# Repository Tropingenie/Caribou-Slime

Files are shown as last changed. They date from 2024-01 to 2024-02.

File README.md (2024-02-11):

SlimeVR PCB using ESP32-C3 and BMI 270
## Methodology
This design is intended to be assembled either completely by hand, or with some PCBA and finished by hand. Component selection is built around this, prioritizing larger form factor SMT components where possible, to ensure compatibility with and minimizing cost of the PCBA, while maintaining relatively simple assembly when done by hand.
## BOM
| Component | Choice | Amount | Cost per | Cost with Shipping | Quick Link |
|:---:|:---:|:---:|:---:|:---:|:---:|
| Microcontroller | ESP32-C3 Supermini Dev Board | 12 | $2.90 | ~$41 | [AliExpress](https://www.aliexpress.com/item/1005005877531694.html), [Datasheet](https://www.tindie.com/products/adz1122/esp32-c3-development-board-esp32-supermini/), [Schematic](https://s11.ax1x.com/2023/06/26/pCUheR1.png) |
| IMU | BMI270 | 12 | $1.75 | ~$26 | [AliExpress](https://www.aliexpress.com/item/1005005001642144.html), [Datasheet](https://www.mouser.ca/datasheet/2/783/bst_bmi270_ds000-2529306.pdf), [Schematic](https://web.archive.org/web/20240115041534/http://cdn.kouno.xyz/pKyF5w64.pdf) |
| Batteries | 603040 800mAh | 10 | $3.50 | ~$31 | [AliExpress](https://www.aliexpress.com/item/1005005413532176.html) |
| Charging Board  | TP4056 USB-C | 15 | $0.329 | ~$5 | [AliExpress](https://www.aliexpress.com/item/1005005708749053.html) |
| Power Switches  | EG1270/MSK-12D19 | 10 | $0.085 | ~$3 | [EG Datasheet](https://www.snapeda.com/parts/EG1270/E-Switch/datasheet/), [MSK Datasheet](http://www.intechswitch.com/products/SideKnobToggleslideswitchseries/641.html), [MSK AliExpress](https://www.aliexpress.com/item/1005006241343643.html) |
| Diodes | B5817W | 50 | | ~$3 | [AliExpress](https://www.aliexpress.com/item/1005005562043696.html), [Datasheet](https://jlcpcb.com/partdetail/Hongjiacheng-B5817W/C7420328) |
| Resistors | 0805 180k 5% (See schematic) | 100 | | ~$2 | [AliExpress](https://www.aliexpress.com/item/4000996637737.html) |
| Resistors | 0805 10k 5% (See schematic)  | 100 | | ~$2 | [AliExpress](https://www.aliexpress.com/item/4000996637737.html) |
| Capacitors | 0805 100nF 5% (See schematic)| 100 | | ~$2 | [AliExpress](https://www.aliexpress.com/item/1005006285113165.html) |
| PCB | Upload Gerbers | 5 | $0.538 | ~$4 | [JLCPCB](https://jlcpcb.com/) |
## Acknowledgement
EDA files are from various sources, since there is no point in reinventing the wheel. At this stage, they are assumed to be correct, but have not been tested for accuracy.
- [BMI270](https://www.snapeda.com/parts/BMI270/Bosch%20Sensortec/view-part/) from SnapEDA
- [ESP32 C2 SuperMini](https://www.snapeda.com/parts/ESP32-C3%20SuperMini/Espressif%20Systems/view-part/) from SnapEDA
- [TP4056 Charging Board](https://www.youtube.com/watch?v=d5fERUHO1Lw) footprint copied from YouTube, schematic by observation
- [EG1270](https://www.snapeda.com/parts/EG1270/E-Switch/view-part/) from SnapEDA

Assistance from various sources was used in this project, in addition to readily available datasheets. In particular, the following people and sources have contributed to this project:
- [SlimeVR Docs](https://docs.slimevr.dev/diy/index.html) for general SlimeVR schematics
- [SlimeVR Discord](https://discord.gg/SlimeVR) for general assisance
- [KounoLab](https://store.kouno.xyz/products/bmi270-breakout-board) for additional BMI270 schematics
- @simp_360 on Discord for diode and passive component selection
- [Lupinixx](https://github.com/Lupinixx/SlimeVR-Hyperion-BMI160-PCB) and [Smeltie](https://github.com/Smeltie/Hyperion) for the Hyperion case and board outline

## License
This project is licensed under the CERN Open Hardware Licence Version 2 - Strongly Reciprocal. See [LICENSE](LICENSE) for full DEP5 formatted REUSE compliant listing of all licensing. For instructions on how to use this design, please refer to the CERN-OHL-S [user guide](cern_ohl_s_v2_user_guide.pdf).

>Copyright Pon Pon 2024.\
This source describes Open Hardware and is licensed under the CERN-OHL-S v2.
You may redistribute and modify this source and make products using it under the terms of the [CERN-OHL-S v2](https://ohwr.org/cern_ohl_s_v2.txt).\
This source is distributed WITHOUT ANY EXPRESS OR IMPLIED WARRANTY, INCLUDING OF MERCHANTABILITY, SATISFACTORY QUALITY AND FITNESS FOR A PARTICULAR PURPOSE. Please see the CERN-OHL-S v2 for applicable conditions.\
Source location: https://github.com/Tropingenie/Caribou-Slime \
As per CERN-OHL-S v2 section 4, should You produce hardware based on this source, You must where practicable maintain the Source Location visible on the silkscreen of the PCB or other products you make using this source.

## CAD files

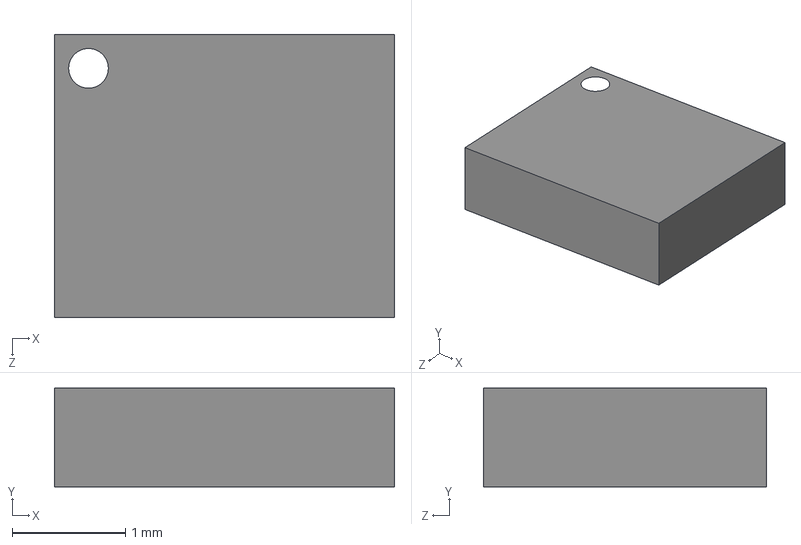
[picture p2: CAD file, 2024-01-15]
eCAD/BMI270/BMI270.step
3.00 x 0.87 x 2.50 mm

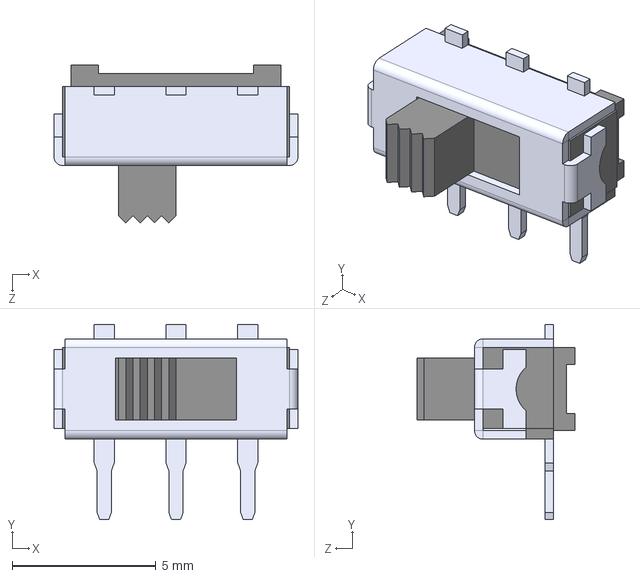
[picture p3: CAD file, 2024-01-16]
eCAD/EG1270/EG1270.step
8.50 x 6.80 x 5.50 mm

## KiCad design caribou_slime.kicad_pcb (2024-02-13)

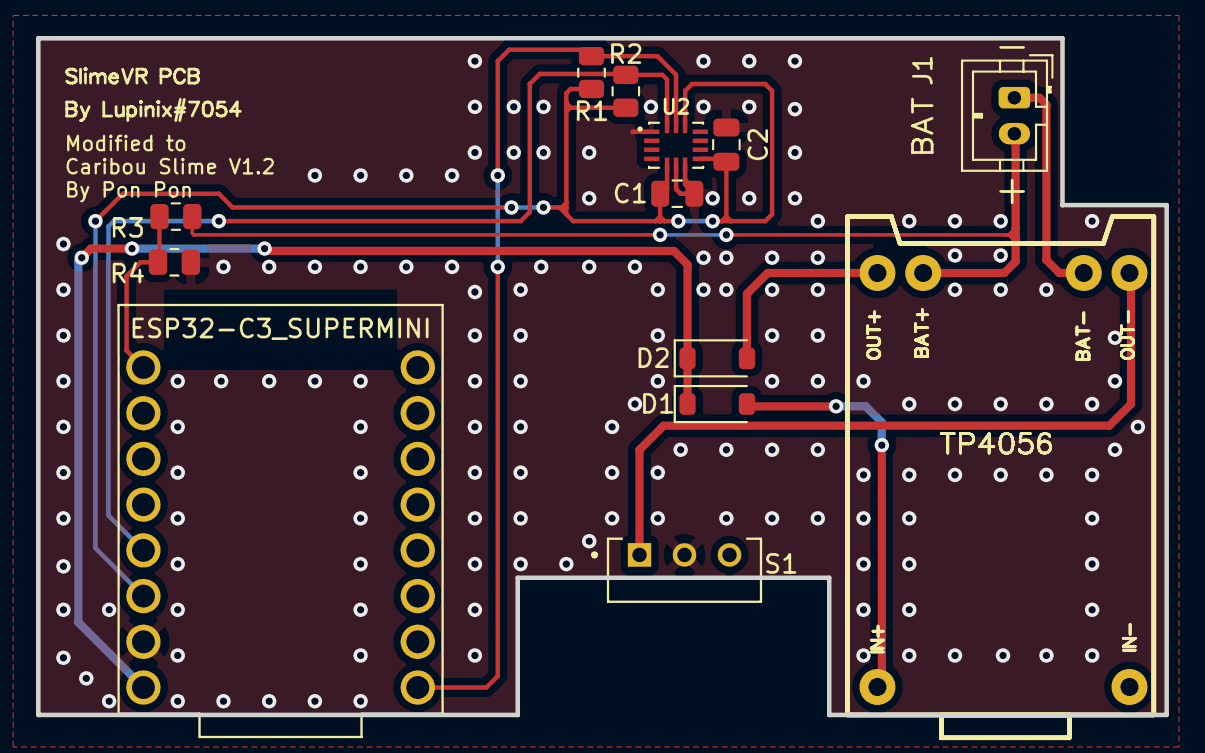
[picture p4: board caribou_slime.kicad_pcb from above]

Board: 2 copper layers, 62.7 x 37.6 mm, 13 parts (0 on the bottom side), 11 nets.

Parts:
C1, C2: 100nF; C_0805_2012Metric
D1, D2: B5817W; D_SOD-123
J1: Conn_01x02_MountingPin; JST_PH_B2B-PH-K_1x02_P2.00mm_Vertical
R1, R2: 10k; R_0805_2012Metric
R3, R4: 180k; R_0805_2012Metric
S1: EG1270; SW_EG1270
U1: ESP32-C3_SUPERMINI; MODULE_ESP32-C3_SUPERMINI
U2: BMI270; XDCR_BMI270
U3: TP4056; TP4056 Charging Board

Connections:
+3V3: C1.1, C2.1, R1.1, R2.1, U1.3.3 (3V3), U2.5 (VDDIO), U2.8 (VDD), U2.12 (CSB)
+5V: D1.1 (K), D2.1 (K), U1.5V
/B+: J1.2, R3.1, U3.5 (B+)
/B-: J1.1, U3.6 (B-)
GND: C1.2, C2.2, R4.2, S1.2, U1.G (GND), U2.1 (SDO), U2.6 (GNDIO), U2.7 (GND)
unnamed: D1.2 (A), U3.1 (+)
unnamed: D2.2 (A), U3.3 (OUT+)
unnamed: R3.2, R4.1, U1.0 (GPIO0)
unnamed: S1.1, U3.4 (OUT-)
SCL: R1.2, U1.5 (GPIO5), U2.13 (SCX)
SDA: R2.2, U1.4 (GPIO4), U2.14 (SDX)

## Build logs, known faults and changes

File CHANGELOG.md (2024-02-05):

#### 1.1 (2024-02-05)
##### Chores

* **git:**  Update gitignore with Outputs folder ([e1761e18](https://github.com/Tropingenie/Caribou-Slime/commit/e1761e188d2f6d708ac8d7a0ce4b8d9b700f2ab1))
* **pcb:**
  *  Clean up SCL trace, stiching vias ([36fab2da](https://github.com/Tropingenie/Caribou-Slime/commit/36fab2da01eddbc8a2c2f9321ec0b02e734b0093))
  *  Run S1 trace ([f5dbebb2](https://github.com/Tropingenie/Caribou-Slime/commit/f5dbebb26b71ab781b65b740ba7b493cb27abcbf))
  *  Clear PCB for rework ([79724f06](https://github.com/Tropingenie/Caribou-Slime/commit/79724f06d09ecba5b7e15c69e1ae2038ea3d9b68))
  *  Clean up 3v3 trace ([33c8f8dc](https://github.com/Tropingenie/Caribou-Slime/commit/33c8f8dc0faf7752790b79c9067acac1a620ce24))
  *  Add stitching vias ([2086238c](https://github.com/Tropingenie/Caribou-Slime/commit/2086238c4812a27943edc295002db64d4f61f880))

##### Documentation Changes

* **pcb:**
  *  Fix silkscreen text ([fce9516e](https://github.com/Tropingenie/Caribou-Slime/commit/fce9516e328b0c797ed55c4b92e85ebc3e1f5b3a))
  *  Prep silk screen for V1.1 Hyperion layout ([3da79978](https://github.com/Tropingenie/Caribou-Slime/commit/3da79978956e21a994be3337dcc98d4a1b6263a4))
  *  Update silkscreen version number ([adf87a9c](https://github.com/Tropingenie/Caribou-Slime/commit/adf87a9cc52d62ae70a44fe4393f7fe04dcc25ed))
  *  Correct attribution and diode silkscreen ([97e8b304](https://github.com/Tropingenie/Caribou-Slime/commit/97e8b3044bba16a783717153758a67535e34dd04))
  *  Add versioning and github to silkscreen ([6df0c895](https://github.com/Tropingenie/Caribou-Slime/commit/6df0c8955d4412fe9c83a9e6ff428d9331b842d1))
* **git:**
  *  Add Hyperion attributions to README ([de8c5598](https://github.com/Tropingenie/Caribou-Slime/commit/de8c5598924c62871d16c71c90c9772a37134501))
  *  Add changelog ([6ed6fb8f](https://github.com/Tropingenie/Caribou-Slime/commit/6ed6fb8fb799e5b07e82560c993f4991915c10c9))

##### New Features

* **pcb:**  Design V1.1 PCB layout ([d03a254f](https://github.com/Tropingenie/Caribou-Slime/commit/d03a254f027ed8a3be3809fd5225acc5b23603d9))

##### Bug Fixes

* **pcb:**
  *  Update GPIO0 connection to voltage divider ([e8315e05](https://github.com/Tropingenie/Caribou-Slime/commit/e8315e059f23269145b51dfc6895d3f81c5e060e))
  *  Add correct JST schematic and footprint ([19320bd5](https://github.com/Tropingenie/Caribou-Slime/commit/19320bd59f4855a179c82c26a0f06b04f38bfdef))
  *  Add keep-out zone around antenna ([a4e4d6b1](https://github.com/Tropingenie/Caribou-Slime/commit/a4e4d6b14058ac6eb4f936a251781c287306000a))
  *  Add correct JST schematic and footprint ([ba236325](https://github.com/Tropingenie/Caribou-Slime/commit/ba236325d222b22f8554df80bf8a3fa0c63cf11f))
* **schematic:**
  *  Correct GPIO0 connection to voltage divider ([4021e6ab](https://github.com/Tropingenie/Caribou-Slime/commit/4021e6ab3e8be55155657b90452c1314c8ec476b))
  *  Switch C1 footprint to 0805 ([e2b43c3f](https://github.com/Tropingenie/Caribou-Slime/commit/e2b43c3ff3bb09d0bedc211e97a49c9b78e96850))
  *  Add 2:1 divider to bat sense ([c737ed53](https://github.com/Tropingenie/Caribou-Slime/commit/c737ed53d258acf4d2d706fad503e8bb672cced0))
  *  Add 2:1 divider to bat sense ([db5c9217](https://github.com/Tropingenie/Caribou-Slime/commit/db5c92171e557cbb750488283881fa9c0f2e7d09))

##### Other Changes

* //github.com/Tropingenie/Caribou-Slime ([68466d78](https://github.com/Tropingenie/Caribou-Slime/commit/68466d783ee6e364831d7c283fe6a95a1b3dda2b))
* **git:**
  *  Clean up missing submodule file path ([f34ac773](https://github.com/Tropingenie/Caribou-Slime/commit/f34ac773b44fcd4dcd26afeea77337c6b1857050))
  *  Add gitignores for npm files ([59695c83](https://github.com/Tropingenie/Caribou-Slime/commit/59695c837662a074b48e74bb377f2cdbfd321c79))

##### Refactors

* **pcb:**  Design V1 PCB for Hyperion ([854ca62b](https://github.com/Tropingenie/Caribou-Slime/commit/854ca62bc941828ca44793224000a3252cfea967))

#### 1.0.0 (2024-01-21)

##### Other Changes

* //github.com/Tropingenie/Caribou-Slime ([dc355974](https://github.com/Tropingenie/Caribou-Slime/commit/dc3559744cfa11d9a080facce75ad9a56f3d934e))
* //github.com/Tropingenie/Caribou-Slime ([9a0361fb](https://github.com/Tropingenie/Caribou-Slime/commit/9a0361fbbde74abe5335792d784baf1033b77d78))

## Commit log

2024-01-15 Initialize Project
    [caribou_slime.kicad_pcb, caribou_slime.kicad_sch]
2024-01-15 Add ESP32 dev board schematic to repo
2024-01-15 Add BMI270 schematic to repo
    [BMI270.step]
2024-01-15 Add ESP32 and BMI270 to schematic
    [caribou_slime.kicad_sch]
2024-01-15 Make TP4056 charging board eCAD files
    [caribou_slime.kicad_pcb, caribou_slime.kicad_sch]
2024-01-16 Add BMI 270 circuit to schematic
    [caribou_slime.kicad_sch]
2024-01-16 Add ucontroller circuit to schematic
    [caribou_slime.kicad_sch]
2024-01-16 Add TP4056 circuit to schematic
    [caribou_slime.kicad_sch]
2024-01-16 Add EG1270 eCAD files to repo
    [EG1270.step]
2024-01-16 Change generic switch for EG1270
    [caribou_slime.kicad_sch]
2024-01-16 Add battery sense, correct I2C connection
    [caribou_slime.kicad_sch]
2024-01-16 Add label on TP4056
    [caribou_slime.kicad_sch]
2024-01-16 Ground SDO on BMI270 to select correct address
    [caribou_slime.kicad_sch]
2024-01-16 Revert I2C to GPIO4/5 to free 8 for LED
    [caribou_slime.kicad_sch]
2024-01-17 Select B5817W diode for charge protect diodes
    [caribou_slime.kicad_sch]
2024-01-17 Switch passives to 0805 SMT for JLCPCB assembly
    [caribou_slime.kicad_sch]
2024-01-20 Create V1 initial PCB layout
    [caribou_slime.kicad_pcb]
2024-01-20 Fix caps placement, fix bat lead pitch
    [caribou_slime.kicad_pcb]
2024-01-20 Add SuperMini schematic to repo
2024-01-20 Update BOM
2024-01-20 Generate Gerbers for V1
    [caribou_slime-B_Cu.gbr, caribou_slime-B_Mask.gbr, caribou_slime-B_Paste.gbr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]
2024-01-21 Finalize V1
    [caribou_slime-B_Cu.gbr, caribou_slime-B_Mask.gbr, caribou_slime-B_Paste.gbr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]
2024-01-21 docs(pcb): Add versioning and github to silkscreen
    [caribou_slime.kicad_pcb]
2024-01-22 other(git) Pull in Hyperion PCB as submodule
2024-01-22 refactor(pcb): Design V1 PCB for Hyperion
    [caribou_slime.kicad_pcb, hyperion.kicad_pcb]
2024-01-22 docs(pcb): Correct attribution and diode silkscreen
    [caribou_slime.kicad_pcb]
2024-01-24 fix(pcb): Add correct JST schematic and footprint
    [caribou_slime.kicad_pcb, caribou_slime.kicad_sch]
2024-01-24 fix(pcb): Add keep-out zone around antenna
    [caribou_slime.kicad_pcb]
2024-01-24 chore(pcb): Add stitching vias
    [caribou_slime.kicad_pcb]
2024-01-24 chore(pcb): Clean up 3v3 trace
    [caribou_slime.kicad_pcb]
2024-01-24 docs(pcb): Update silkscreen version number
    [caribou_slime.kicad_pcb]
2024-02-04 fix(schematic): Add 2:1 divider to bat sense
    [caribou_slime.kicad_sch]
2024-02-04 chore(pcb): Clear PCB for rework
    [caribou_slime.kicad_pcb]
2024-02-04 docs(pcb): Prep silk screen for V1.1 Hyperion layout
    [caribou_slime.kicad_pcb]
2024-02-04 fix(schematic): Switch C1 footprint to 0805
    [caribou_slime.kicad_sch]
2024-02-04 chore(pcb): Run S1 trace
    [caribou_slime.kicad_pcb]
2024-02-04 feat(pcb): Design V1.1 PCB layout
    [caribou_slime.kicad_pcb]
2024-02-04 docs(pcb): Fix silkscreen text
    [caribou_slime.kicad_pcb]
2024-02-05 chore(pcb): Clean up SCL trace, stiching vias
    [caribou_slime.kicad_pcb]
2024-02-05 fix(schematic): Correct GPIO0 connection to voltage divider
    [caribou_slime.kicad_sch]
2024-02-05 fix(pcb): Update GPIO0 connection to voltage divider
    [caribou_slime.kicad_pcb]
2024-02-13 refactor(pcb): Increase TP4056 trace widths to 18 mil
    [caribou_slime.kicad_pcb]
